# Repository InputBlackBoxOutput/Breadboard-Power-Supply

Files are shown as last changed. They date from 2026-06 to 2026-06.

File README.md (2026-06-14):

# Breadboard Power Supply

A convenient power supply to provide power while building and testing analog/digital circuits on a breadboard

## Features
* Snaps right onto a breadboard
* Ships with 2 variants SMD and THT for choice of components
* Input power can be derived from a 12V SMPS via barrel jack or 5V via USB cable
* Switches to switch the output voltages on/off 
* Provides variable voltage 

## Technical specification
* *Output voltages:* Fixed: 5 ± 0.150V and 3.3 ± 0.099V and Variable: 1.25V to ≈Vsupply 
* *Output currents:* 1.1A max for each voltage when connected to a 12V 2A SMPS and 500 mA total when connected to USB

### Caution: Do not connect current hungry components when input power is provided via USB 

## 3D Render
| SMD variant | THT variant |
|--|--|
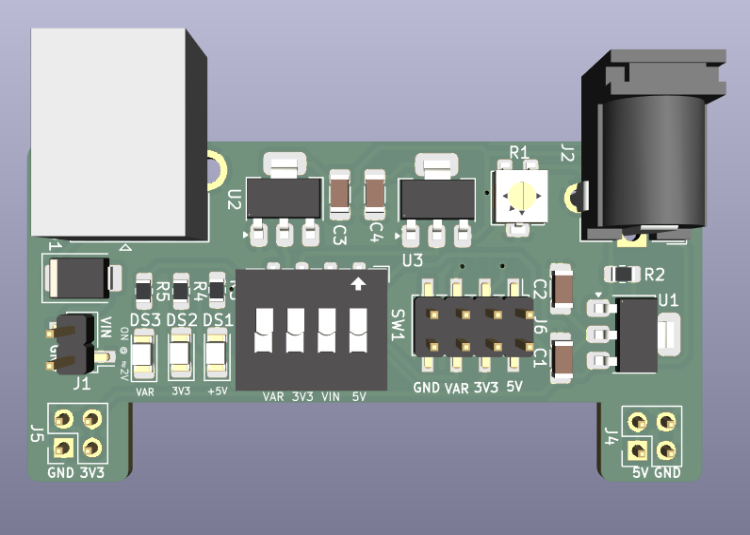
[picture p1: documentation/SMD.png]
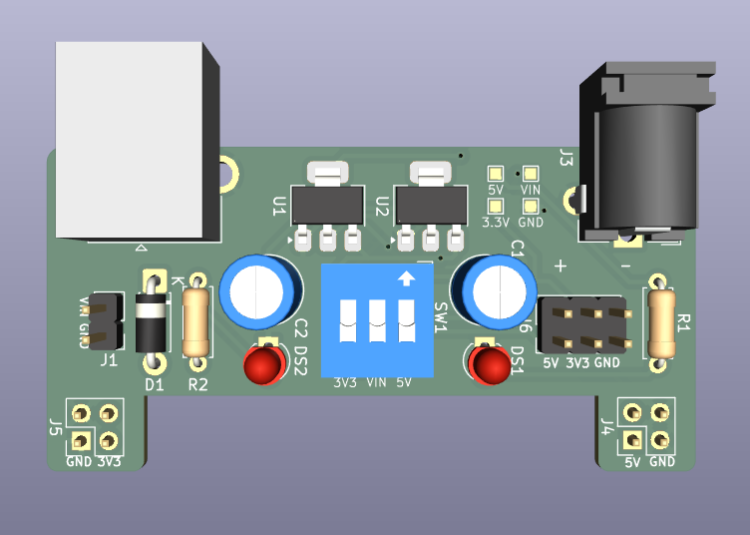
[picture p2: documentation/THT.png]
|||

### Made with lots of ⏱️, 📚 and ☕ by InputBlackBoxOutput

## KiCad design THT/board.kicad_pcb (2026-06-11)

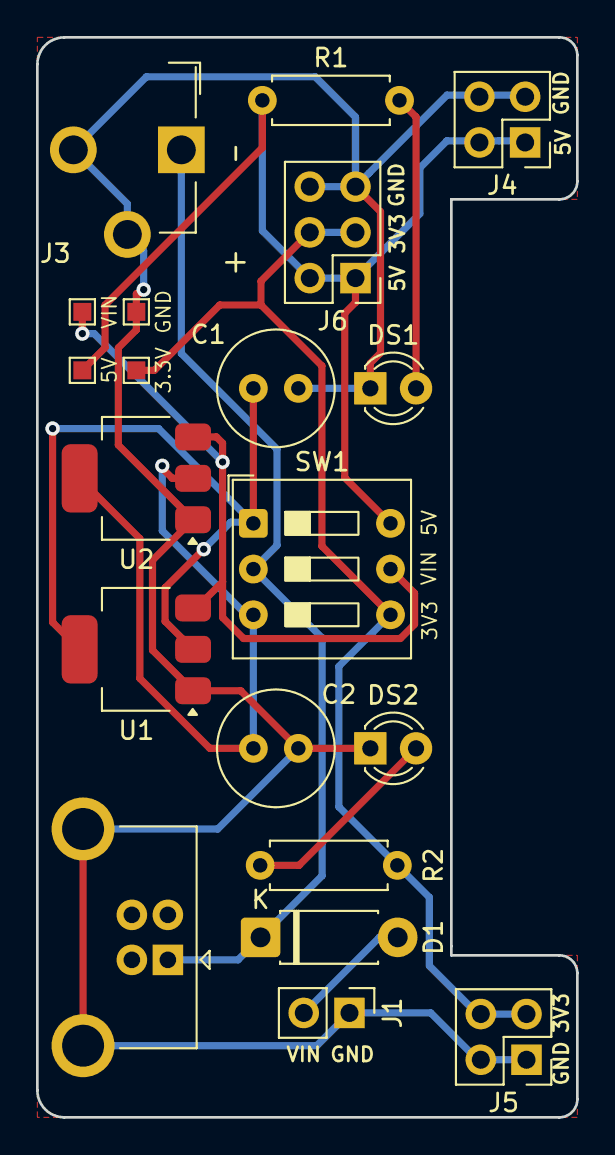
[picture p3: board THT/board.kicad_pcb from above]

Board: 2 copper layers, 30.0 x 60.0 mm, 20 parts (0 on the bottom side), 10 nets.

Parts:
3.3V, 5V: TestPoint; TestPoint_Pad_1.0x1.0mm
C1, C2: 22uF; C_Radial_D6.3mm_H11.0mm_P2.50mm
D1: 1N4007; D_DO-41_SOD81_P7.62mm_Horizontal
DS1, DS2: LED; LED_D3.0mm
GND: TestPoint; TestPoint_Pad_1.0x1.0mm
J1: 9V Battery; PinHeader_1x02_P2.54mm_Vertical
J2: USB_B; USB_B_OST_USB-B1HSxx_Horizontal
J3: Barrel_Jack_Switch; BarrelJack_CUI_PJ-102AH_Horizontal
J4: 1; PinHeader_2x02_P2.54mm_Vertical
J5: 2; PinHeader_2x02_P2.54mm_Vertical
J6: 3; PinHeader_2x03_P2.54mm_Vertical
R1: 2.2k; R_Axial_DIN0207_L6.3mm_D2.5mm_P7.62mm_Horizontal
R2: 1.5k; R_Axial_DIN0207_L6.3mm_D2.5mm_P7.62mm_Horizontal
SW1: SW_DIP_x03; SW_DIP_SPSTx03_Slide_9.78x9.8mm_W7.62mm_P2.54mm
U1: AMS1117-5.0; SOT-223-3_TabPin2
U2: AMS1117-3.3; SOT-223-3_TabPin2
VIN: TestPoint; TestPoint_Pad_1.0x1.0mm

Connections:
+3.3V: 3.3V.1 (1_1), J5.3, J5.4, J6.3, J6.4, R2.1, SW1.4
+5V: 5V.1 (1_1), J4.1, J4.2, J6.1, J6.2, R1.1, SW1.6
/3.3V: C2.1, SW1.3, U2.2 (VO)
/5V: C1.1, SW1.1, U1.2 (VO)
/VIN: SW1.5, U1.3 (VI), U2.3 (VI), VIN.1 (1_1)
GND: C1.2, C2.2, DS1.1 (K), DS2.1 (K), GND.1 (1_1), J1.1, J2.5 (Shield), J3.2, J3.3, J4.3, J4.4, J5.1, J5.2, J6.5, J6.6, U1.1 (GND), U2.1 (GND)
unnamed: D1.2 (A), J1.2
unnamed: DS1.2 (A), R1.2
unnamed: DS2.2 (A), R2.2
VDC: D1.1 (K), J2.1 (VBUS), J3.1, SW1.2

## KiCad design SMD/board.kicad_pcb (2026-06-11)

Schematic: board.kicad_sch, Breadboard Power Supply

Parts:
C1: 0.1uF; C_1206_3216Metric_Pad1.33x1.80mm_HandSolder
C2: 1uF; C_1206_3216Metric_Pad1.33x1.80mm_HandSolder
C3, C4: 22uF; C_1206_3216Metric_Pad1.33x1.80mm_HandSolder
D1: SS22T3G; D_SMB
DS1, DS2, DS3: LED; LED_1206_3216Metric_Pad1.42x1.75mm_HandSolder
J1: 9V Battery; PinHeader_1x02_P2.54mm_Vertical_SMD_Pin1Left
J2: Barrel_Jack_Switch; BarrelJack_CUI_PJ-102AH_Horizontal
J3: USB_B; USB_B_OST_USB-B1HSxx_Horizontal
J4: 1; PinHeader_2x02_P2.54mm_Vertical
J5: 2; PinHeader_2x02_P2.54mm_Vertical
J6: Conn_02x04_Odd_Even; PinHeader_2x04_P2.54mm_Vertical_SMD
R1: 5k; Potentiometer_Bourns_3314G_Vertical
R2: 240R; R_0805_2012Metric_Pad1.20x1.40mm_HandSolder
R3: 2.2k; R_0805_2012Metric_Pad1.20x1.40mm_HandSolder
R4: 1k; R_0805_2012Metric_Pad1.20x1.40mm_HandSolder
R5: 820R; R_0805_2012Metric_Pad1.20x1.40mm_HandSolder
SW1: SW_DIP_x04; SW_DIP_SPSTx04_Slide_9.78x12.34mm_W8.61mm_P2.54mm
TP1, TP2, TP3, TP4, TP5: TestPoint; TestPoint_Pad_1.0x1.0mm
U1: LM317; SOT-223-3_TabPin2
U2: AMS1117-5.0; SOT-223-3_TabPin2
U3: AMS1117-3.3; SOT-223-3_TabPin2

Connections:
+3.3V: J5.3, J5.4, J6.3, J6.4, R4.1, SW1.6, TP4.1 (1_1)
+5V: J4.1, J4.2, J6.1, J6.2, R3.1, SW1.8, TP3.1 (1_1)
/3.3V: C4.1, SW1.3, U3.2 (VO)
/5V: C3.1, SW1.1, U2.2 (VO)
/V: J6.5, J6.6, R5.1, SW1.5, TP5.1 (1_1)
/VIN: C1.1, SW1.7, TP1.1 (1_1), U1.3 (VI), U2.3 (VI), U3.3 (VI)
/VOUT: C2.1, R2.1, SW1.4, U1.2 (VO)
GND: C1.2, C2.2, C3.2, C4.2, DS1.1 (K), DS2.1 (K), DS3.1 (K), J1.1, J2.2, J2.3, J3.4 (GND), J3.5 (Shield), J4.3, J4.4, J5.1, J5.2, J6.7, J6.8, R1.2, TP2.1 (1_1), U2.1 (GND), U3.1 (GND)
unnamed: D1.2 (A), J1.2
unnamed: DS1.2 (A), R3.2
unnamed: DS2.2 (A), R4.2
unnamed: DS3.2 (A), R5.2
unnamed: R1.1, R2.2, U1.1 (ADJ)
VDC: D1.1 (K), J2.1, J3.1 (VBUS), SW1.2

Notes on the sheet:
text sample 3
RED
-------------------------------------------- # Current limiting resistor R = (Vs - Vled)/Iled Vled-red = 2V typical R @ 5V = 2.2k Iled = 1.3 mA R @ 3.3V = 1.5k Iled = 1.3 mA R @ var = 820R Iled =10.9 mA (At Vs-max = 12V) --------------------------------------------
Use 2k pot if available
# Reverse voltage protection diode Imax = 2A Vrev-max = 20V Vf = 0.3V - 0.4V for ≈1A --------------------------------------------
Variable power supply
Output connectors
Input connectors
# Variable voltage supply Vout = 1.25 * (1+ (R2/R1)) Vout-max = Vin = 12V Substituting Vout = 12V and R1 = 240 ohm we get R2 ≈ 2 kohm --------------------------------------------
Test points
Design notes:
Power control switches
Check polarity
Voltage regulators
LED indicators
AMS-1117 voltage regulators features - Low dropout voltage - Both 5V and 3.3V variant available - Maximum current = 1.1 A

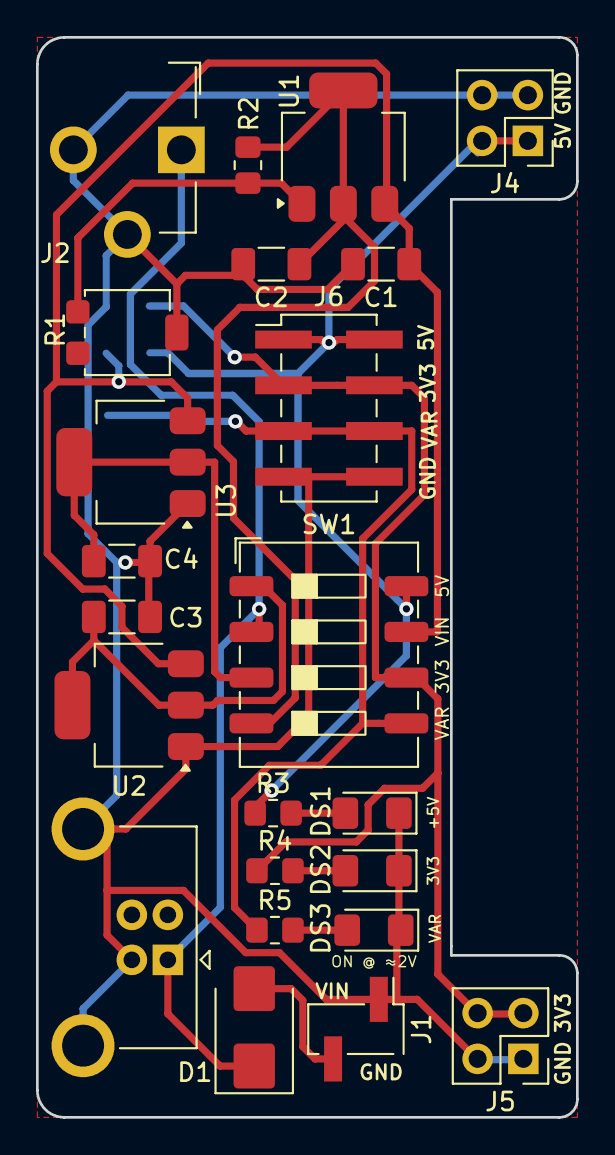
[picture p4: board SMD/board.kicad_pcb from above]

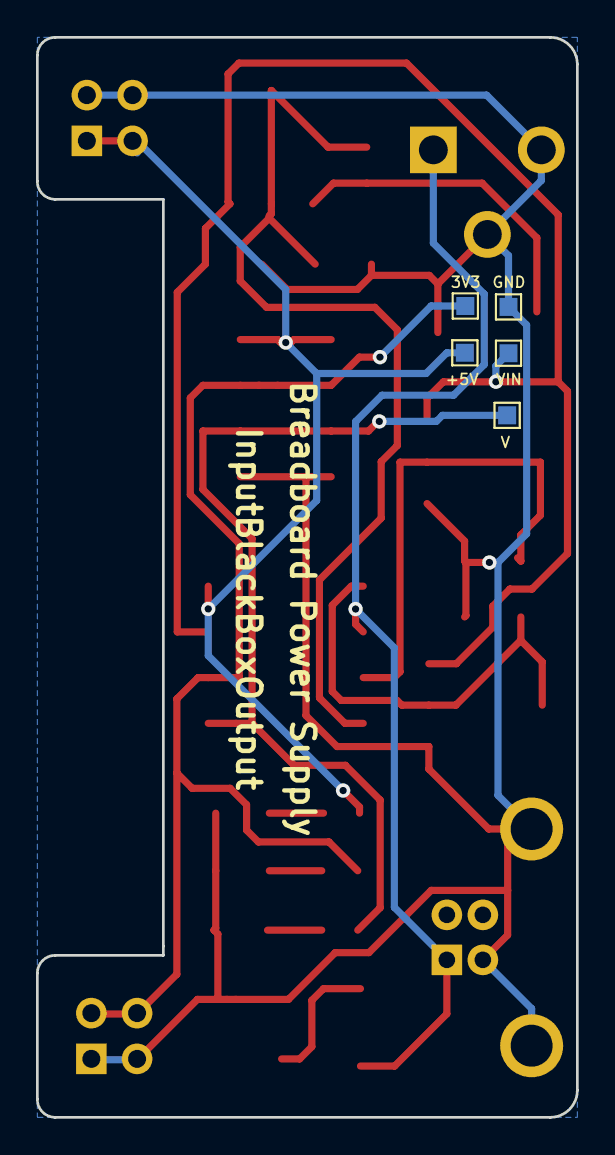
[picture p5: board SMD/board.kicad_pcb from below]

Board: 2 copper layers, 30.0 x 60.0 mm, 28 parts (5 on the bottom side), 14 nets.

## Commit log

2020-11-13 Schematic and PCB design added
    [Breadboard_Power_Supply.dsn, Breadboard_Power_Supply.kicad_pcb, Breadboard_Power_Supply.sch]
2020-11-14 Gerber files and list of components added
    [Breadboard_Power_Supply-B_Cu.gbl, Breadboard_Power_Supply-B_Mask.gbs, Breadboard_Power_Supply-B_Paste.gbp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]
2020-11-14 Markings improved
    [Breadboard_Power_Supply.kicad_pcb]
2020-12-08 Images resized
    [Breadboard_Power_Supply-B_Cu.gbl, Breadboard_Power_Supply-B_Mask.gbs, Breadboard_Power_Supply-B_Paste.gbp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]
2021-06-07 3D models added to PCB
    [2.1mm_barrel_jack.step, Breadboard_Power_Supply.kicad_pcb, USB_type_b_receptacle.step]
2021-06-07 Changed most footprints to SMD + Variable voltage
    [Breadboard_Power_Supply-B_Cu.gbl, Breadboard_Power_Supply-B_Mask.gbs, Breadboard_Power_Supply-B_Paste.gbp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]
2021-06-08 Protection diode changed + Datasheets
    [Breadboard_Power_Supply.kicad_pcb, Breadboard_Power_Supply.sch]
2021-06-12 Calculations added
    [Breadboard_Power_Supply.sch]
2021-06-12 Gerber files and component list updated
    [Breadboard_Power_Supply-B_Cu.gbl, Breadboard_Power_Supply-B_Mask.gbs, Breadboard_Power_Supply-B_Paste.gbp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]
2022-07-03 Repository reorganized
    [Breadboard_Power_Supply-B_Cu.gbl, Breadboard_Power_Supply-B_Mask.gbs, Breadboard_Power_Supply-B_Paste.gbp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]
2026-05-02 Restructure repository
    [BOM.csv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]
2026-06-11 SMD Kicad 10
    [board.kicad_pcb, board.kicad_sch]
2026-06-11 THT Kicad 10
    [BOM.csv, board.kicad_pcb, board.kicad_sch]
